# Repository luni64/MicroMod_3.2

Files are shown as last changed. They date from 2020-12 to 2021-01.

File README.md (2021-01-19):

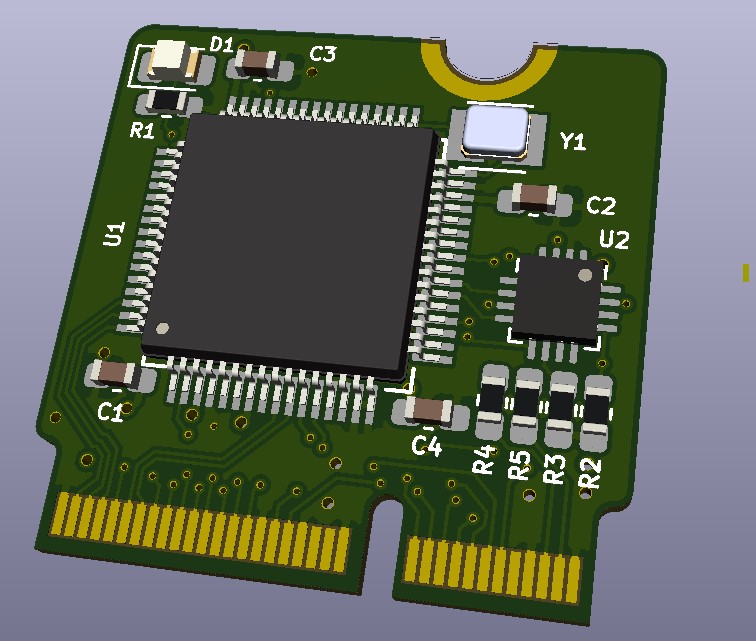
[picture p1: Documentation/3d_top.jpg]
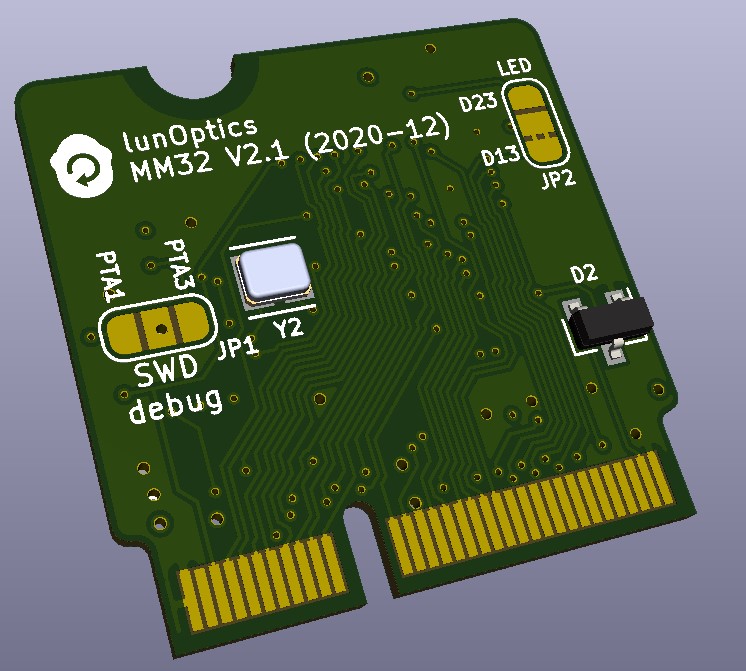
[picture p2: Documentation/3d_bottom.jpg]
3d bottom
 

# MM32
Experimental NXP MK20DX256 controller board compatible to the SparkFun MicroMod (https://www.sparkfun.com/micromod) system and the [PJRC Teensyduino](https://www.pjrc.com/teensy/teensyduino.html) ecosystem. I.e., the board fits on the SparkFun MicroMod carriers and is able to run firmware written for a Teensy 3.2.

The MM32 board utilizes the un-brickable PJRC bootloader, preprogrammed on the MKL02 chip. Please note: You need to buy the bootloader directly from PJRC (https://www.pjrc.com/store/ic_mkl02.html). It won't work with an empty MKL02.

See here https://github.com/luni64/mmStep for a compatible MicroMode stepper driver board.

## Key features:
- Contiguous **8bit port** routed to BUS0-BUS7 (Teensy: PTD0 - PTD7)
- **Two differential ADCs** mapped onto A0/A1 and ADC_D+ ADC_D-
- **True DAC** on PWM_0
- Two **UARTS** (Serial1, Serial2)
- **SPI** interface
- **CAN** Bus
- **Real time clock (RTC)**: 32.679KHz crystal and V_Bat / BAT_VIN/3
supported
- SWD_DIO, SWD_CKL, **debug interface** (bootloader chip can be disabled with a solder bridge on the back side)
- LED pin selectable (solder bridge) between D13 and D23
- Layout optimized for hand soldering

## Functional Pinout

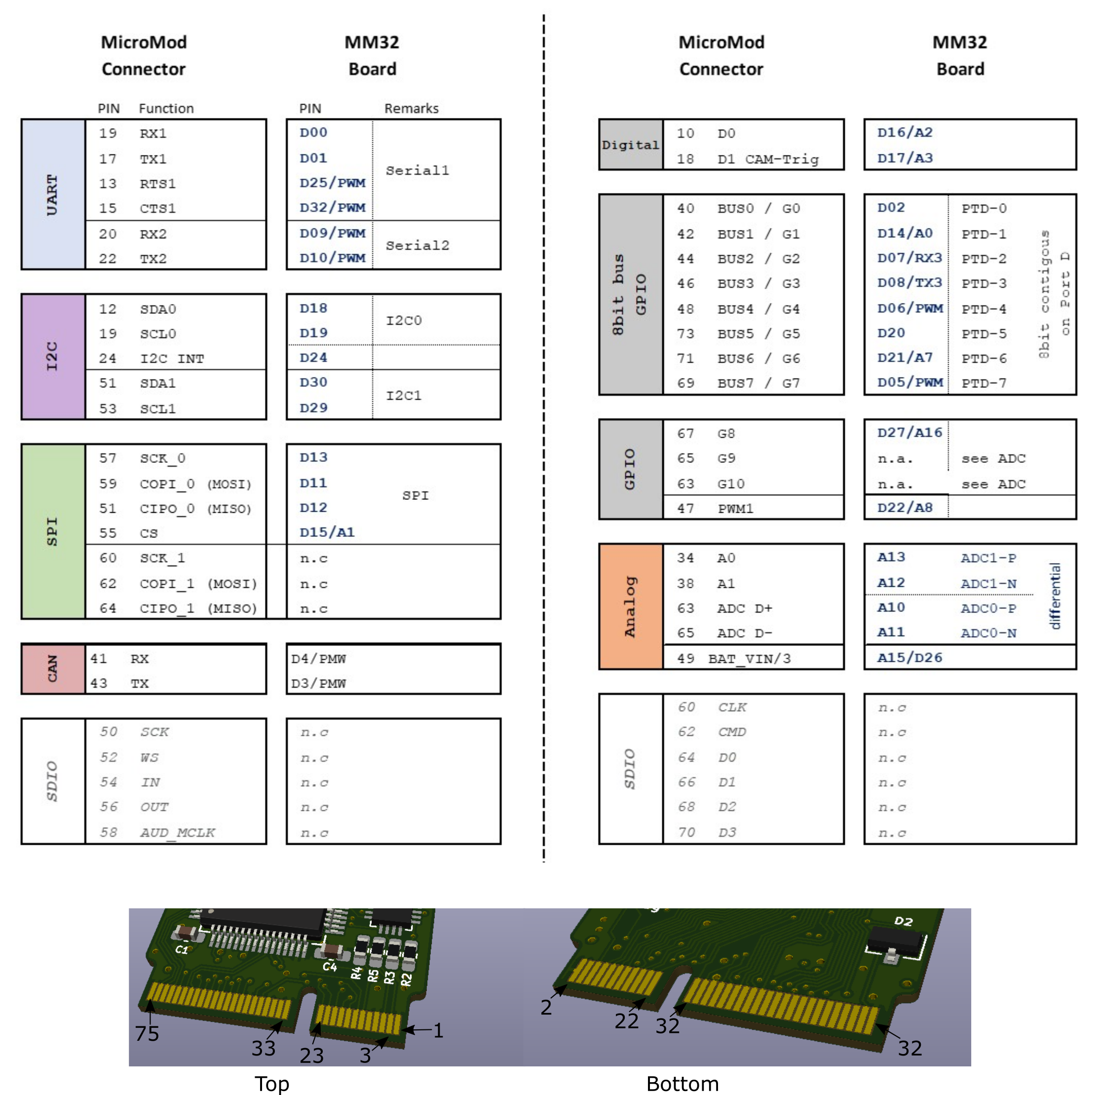
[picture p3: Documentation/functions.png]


## Production data

### PCB
Gerbers and drill files for the 4 layer, 0.8mm board can be found in the [KiCad/production](/KiCad/Production) folder. Production cost at Chinese board houses are currently (12-2020) less than USD 10 for 10 pieces plus shipping.

### Parts
Here a [link](https://octopart.com/bom-tool/5AbwHvxe) to an Octopart BOM
containing live updated prices and availability from major distributors. It also   provides links to datasheets, and technical information and alternative parts.
### Documentation
Schematic, pictures, pinouts and datasheets can be found in the documentation folder.

### Assembly
If you have experience in soldering SMD parts the assembly is straight forward. You don't need any special equipment. A standard 50W soldering iron (I use [that one](https://www.weller-tools.com/professional/EUR/en/Professional/Soldering+technology/Soldering+irons/Low-voltage+soldering+irons/Magnastat/TCP+24+) ) a magnifying glass (something like [this]( https://www.aliexpress.com/i/4000270805536.html)) and cheap head worn loupe glasses (e.g. [those](https://www.amazon.com/AORAEM-Magnifier-Glasses-Light-Extensions/dp/B01AJOD03A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)) are absolutely sufficient. Don't use a pinpoint soldering tip. You need something to transport heat quickly which is best done by a relatively large tip as shown in the video below. 

The only part I found a bit difficult to solder is the small bootloader chip (QFN16). The pads on the board are sufficiently long to solder the chip by hand in principle. However, it is a bit tedious to precisely align the chip to the pads. Start with soldering one pin, then control position and align the chip until it fits. It is helpful to apply some flux paste below the chip which will keep it in place during the alignment. Alternatively you can solder it with a hot air gun.

The rest of the parts are small but easy to solder.

Here a video showing the assembly:

MM32Assembly (https://www.youtube.com/watch?v=CCVqATbAmtM)

## Firmware

The [firmware folder](/Firmware) contains a header defining the
MicroMod <-> Teensyduino pin mappings and a helper class to access the
8bit BUS.

## Debug configuration

You can disable the bootloader by grounding its reset pin. To do so you
need to close the solder bridge on the bottom of the board as shown here:

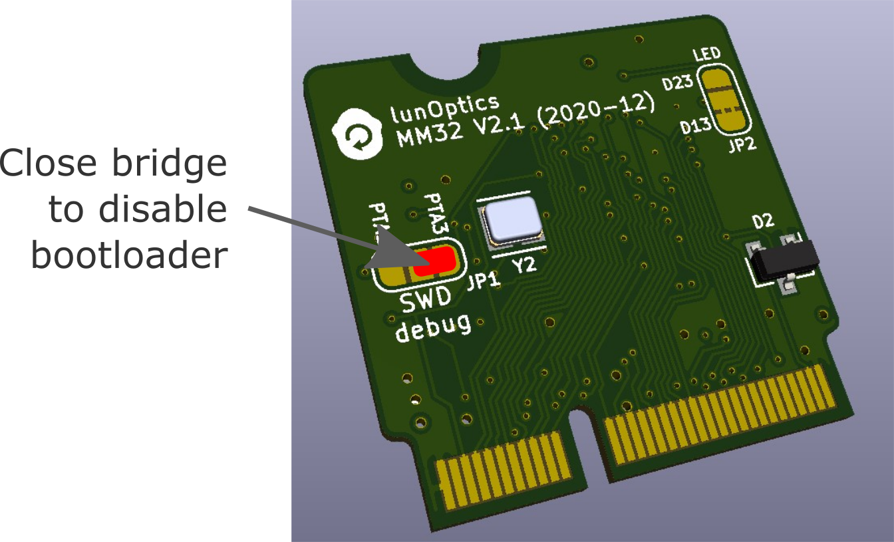
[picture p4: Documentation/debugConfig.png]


You can then connect a debug probe (e.g. a JLink-Mini EDU) to the debug
header on the carrier board.

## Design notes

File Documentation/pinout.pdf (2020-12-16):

Teensy | | | | | Teensy
n.a | 2 | 3V3 | GND | 1 | n.a
n.c | 4 | 3V3 EN | USB D+ | 3 | USB-P
RESET | 6 | /RESET | USB D- | 5 | USB-N
A17 / D28 | 8 | G11 / SWDSWO | GND | 7 | n.a
D16 | 10 | D0 | USB_VIN | 9 | n.c.
D18 | 12 | I2C SDA0 | BOOT | 11 | BL PTB2
D19 | 14 | I2C SCL0 | UART RTS1 | 13 | D25
D24 | 16 | I2C INT | UART CTS1 | 15 | D32
A3 / D17 | 18 | D1 / CAM Trig | UART TX1 | 17 | D1 / TX1
D9 | 20 | UART RX2 | UART RX1 | 19 | D0 / RX1
D10 | 22 | UART TX2 | JTAG SWDCK | 21 | PTA6
| 24 | | JTAG SWDIO | 23 | PTA7
26 25
28 27
30 29
DAC | 32 | PWM 0 | | 31
A13 | 34 | A0 | GND | 4 | n.a
n.a | 36 | GND | USBHOST D- | 35 | n.c
A12 | 38 | A1 | USBHOST D+ | 37 | n.c
PTD0 D02 | 40 | BUS 0 / G0 | GND | 39 | n.a
PTD1 D14 | 42 | BUS 1 / G1 | CAN_RX | 41 | D4
PTD2 D07 | 44 | BUS 2 / G2 | CAN_TX | 43 | D3
PTD3 D08 | 46 | BUS 3 / G3 | GND | 45 | n.a
PTD4 D06 | 48 | BUS 4 / G4 | PWM1 | 47 | D22 / A8
n.c | 50 | I2S_SCK | BAT_VIN/3 | 49 | D26 / A15
n.c | 52 | I2S_WS | I2C SDA1 | 51 | D30
n.c | 54 | I2S_IN | I2C SCL1 | 53 | D29
n.c | 56 | I2S_OUT | SPI_CS | 55 | D15
n.c | 58 | AUD_MCLK(0) | SPI SCK | 57 | D13
n.c | 60 | SPI_SCK1 / SDIO_CLK | (MOSI) SPI COPI | 59 | D11
n.c | 62 | SPI COPI1 / SDIO_CMD | (MISO) SPI CIPO | 61 | D12
n.c | 64 | SPI CIPO1 / SDIO_D0 | ADC_D+ | 63 | A10 ADC0-P
n.c | 66 | SDIO_D1 | ADC_D- | 65 | A11 ADC0-N
n.c | 68 | SDIO_D2 | G8 | 67 | D27 / A16
n.c | 70 | SPI CS1 / SDIO_D3 | BUS7 / G7 | 69 | D05 PTD7
n.c | 72 | RTC 3V BAT | BUS6 / G6 | 71 | D21 PTD6
n.a | 74 | 3V3 | BUS5 / G5 | 73 | D20 PTD5
GND | 75 | n.a Serial2 | Serial 1 JTAG I2C 0

n.a

Key
Key

n.a

## MicroMod Pinout

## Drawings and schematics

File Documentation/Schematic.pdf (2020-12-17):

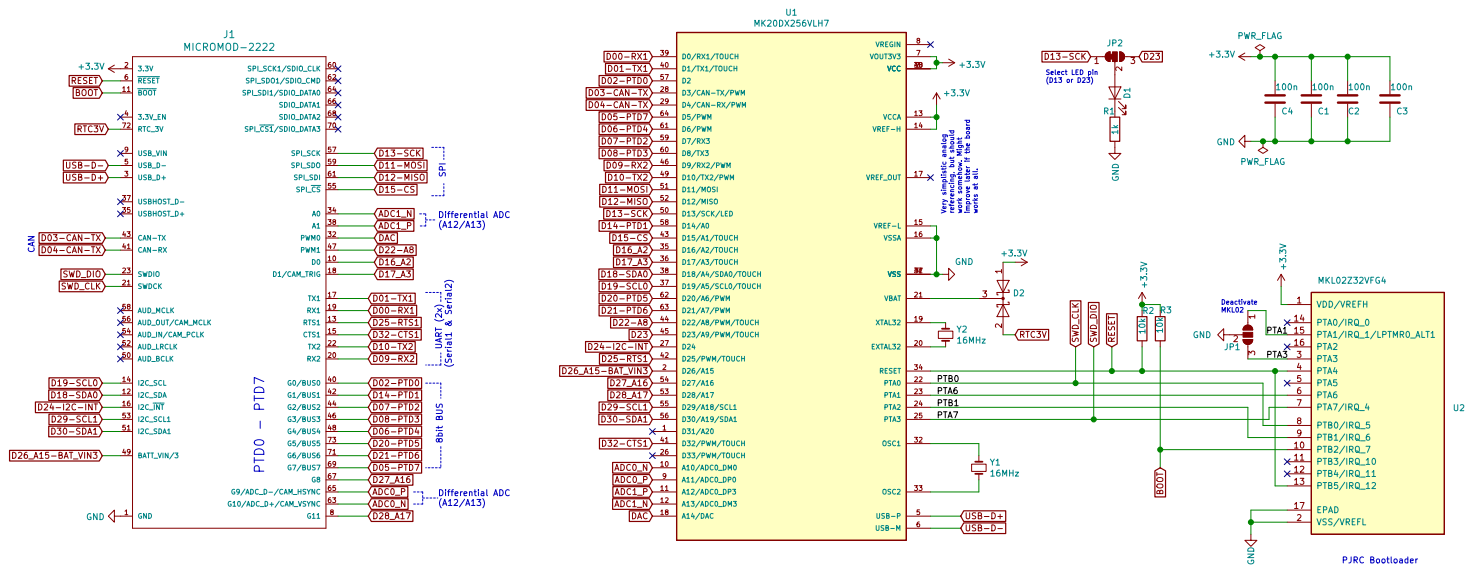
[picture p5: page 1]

D07-PTD2 ADC1_N
(uses Sparkfun recommend connector pin assignment) Similar to T3.2 GND

File: TeensyMM.sch Sheet: / Lunoptics

Id: 1/1 Title: MicroMode32 experimental board

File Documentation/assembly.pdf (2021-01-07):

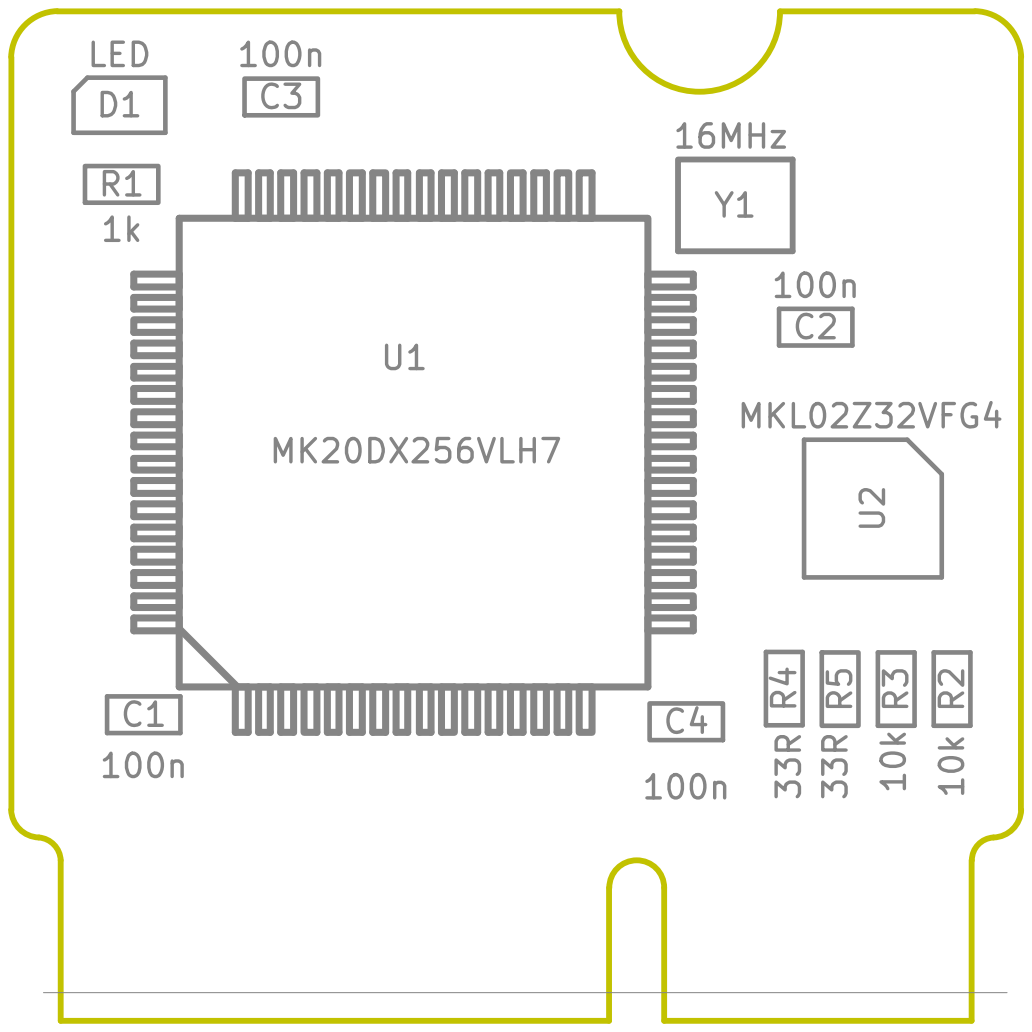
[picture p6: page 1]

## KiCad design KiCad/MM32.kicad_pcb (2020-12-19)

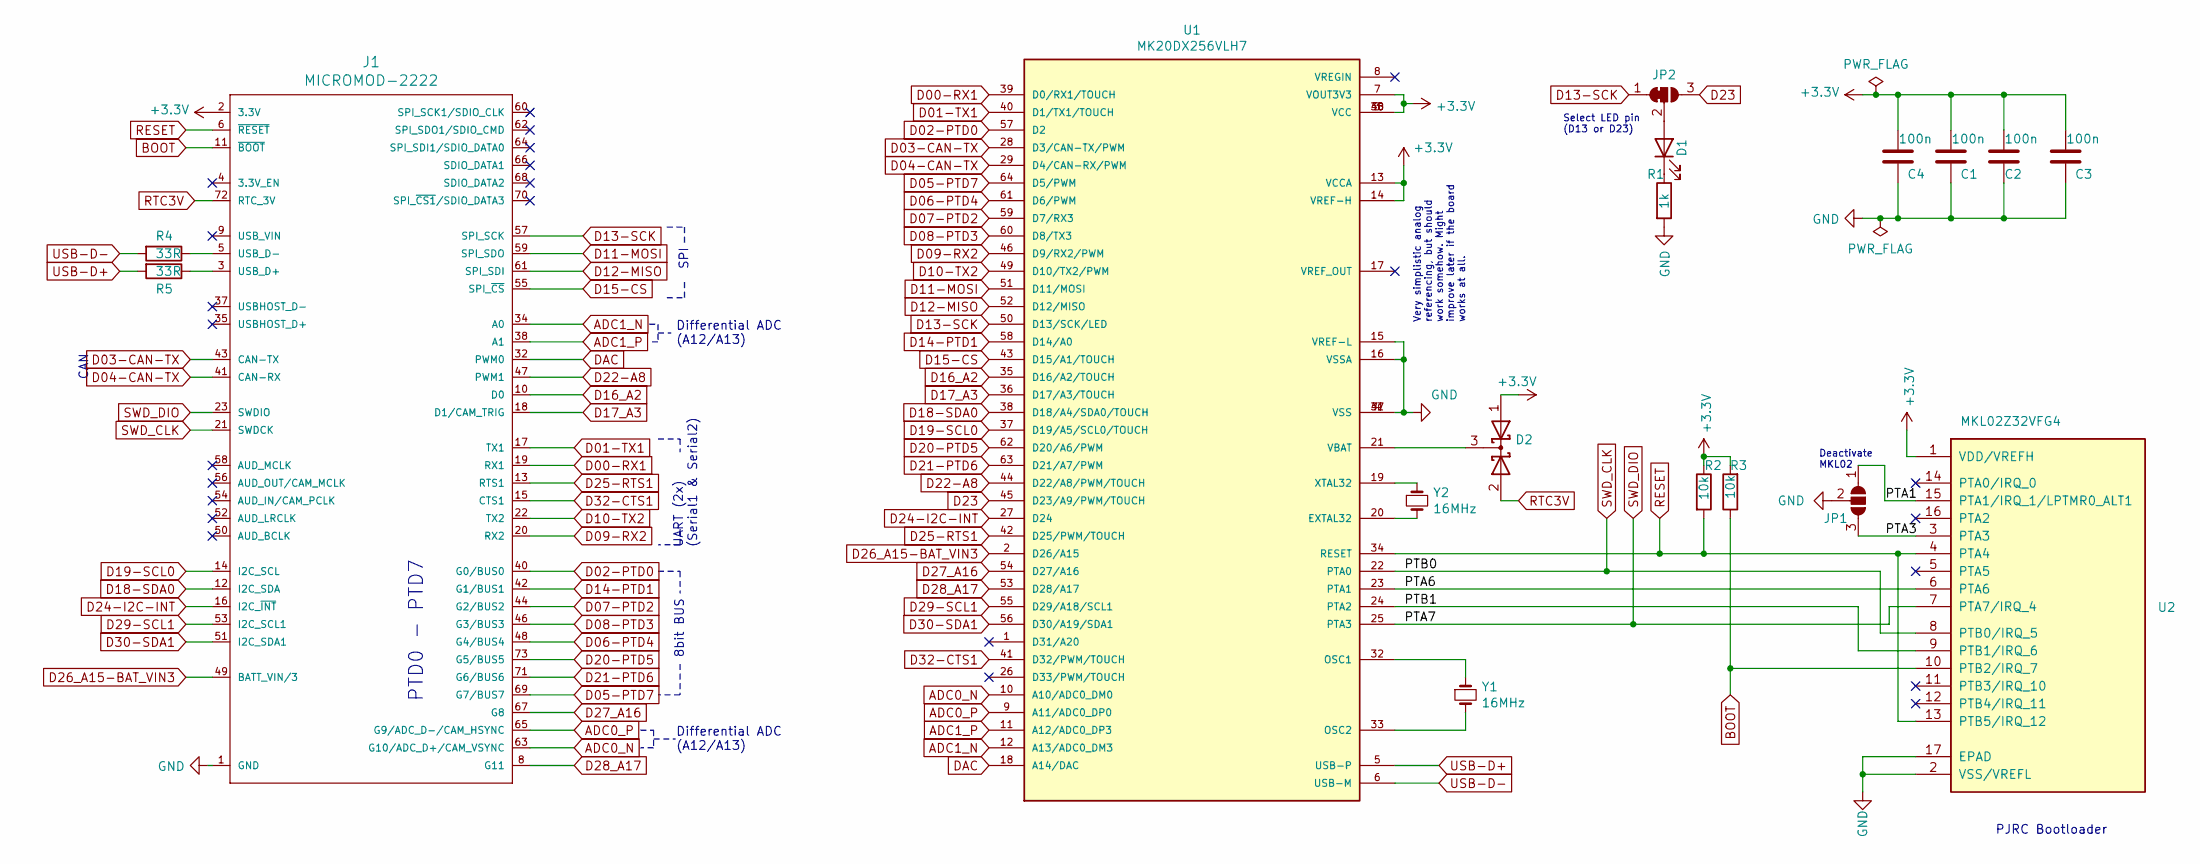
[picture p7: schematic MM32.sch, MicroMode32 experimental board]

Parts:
C1, C2, C3, C4: 100n; C_0603_1608Metric_Pad1.08x0.95mm_HandSolder
D1: LED; LED_0805_2012Metric_Pad1.15x1.40mm_HandSolder
D2: D_Schottky_x2_KCom_AAK; SOT-23
J1: MICROMOD-2222; M.2-CARD-E-22
JP1: SolderJumper_3_Open; SolderJumper-3_P1.3mm_Open_RoundedPad1.0x1.5mm
JP2: SolderJumper_3_Bridged12; SolderJumper-3_P1.3mm_Bridged12_RoundedPad1.0x1.5mm
R1: 1k; R_0603_1608Metric_Pad1.05x0.95mm_HandSolder
R2, R3: 10k; R_0603_1608Metric_Pad1.05x0.95mm_HandSolder
R4, R5: 33R; R_0603_1608Metric_Pad1.05x0.95mm_HandSolder
U1: MK20DX256VLH7; QFP50P1200X1200X160-64N
U2: MKL02Z32VFG4; QFN-16-1EP_3x3mm_P0.5mm_EP1.9x1.9mm
Y1, Y2: 16MHz; OSC_XRCHA16M000F0A01R0

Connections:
+3V3: C1.1, C2.1, C3.1, C4.1, D2.1 (A), J1.2 (3.3V), J1.74 (3.3V), R2.1, R3.2, U1.3 (VCC), U1.7 (VOUT3V3), U1.13 (VCCA), U1.14 (VREF-H), U1.30 (VCC), U1.48 (VCC), U2.1 (VDD/VREFH)
/PTA1: JP1.1 (A), U2.15 (PTA1/IRQ_1/LPTMR0_ALT1)
/PTA3: JP1.3 (B), U2.3 (PTA3)
/PTA6: U1.23 (PTA1), U2.6 (PTA6)
/PTB1: U1.24 (PTA2), U2.9 (PTB1/IRQ_6)
ADC0_N: J1.63 (G10/ADC_D+/CAM_VSYNC), U1.10 (A10/ADC0_DM0)
ADC0_P: J1.65 (G9/ADC_D-/CAM_HSYNC), U1.9 (A11/ADC0_DP0)
ADC1_N: J1.34 (A0), U1.12 (A13/ADC0_DM3)
ADC1_P: J1.38 (A1), U1.11 (A12/ADC0_DP3)
BOOT: J1.11 (~BOOT~), R3.1, U2.10 (PTB2/IRQ_7)
D00-RX1: J1.19 (RX1), U1.39 (D0/RX1/TOUCH)
D01-TX1: J1.17 (TX1), U1.40 (D1/TX1/TOUCH)
D02-PTD0: J1.40 (G0/BUS0), U1.57 (D2)
D03-CAN-TX: J1.43 (CAN-TX), U1.28 (D3/CAN-TX/PWM)
D04-CAN-TX: J1.41 (CAN-RX), U1.29 (D4/CAN-RX/PWM)
D05-PTD7: J1.69 (G7/BUS7), U1.64 (D5/PWM)
D06-PTD4: J1.48 (G4/BUS4), U1.61 (D6/PWM)
D07-PTD2: J1.44 (G2/BUS2), U1.59 (D7/RX3)
D08-PTD3: J1.46 (G3/BUS3), U1.60 (D8/TX3)
D09-RX2: J1.20 (RX2), U1.46 (D9/RX2/PWM)
D10-TX2: J1.22 (TX2), U1.49 (D10/TX2/PWM)
D11-MOSI: J1.59 (SPI_SDO), U1.51 (D11/MOSI)
D12-MISO: J1.61 (SPI_SDI), U1.52 (D12/MISO)
D13-SCK: J1.57 (SPI_SCK), JP2.1 (A), U1.50 (D13/SCK/LED)
D14-PTD1: J1.42 (G1/BUS1), U1.58 (D14/A0)
D15-CS: J1.55 (SPI_~CS~), U1.43 (D15/A1/TOUCH)
D16_A2: J1.10 (D0), U1.35 (D16/A2/TOUCH)
D17_A3: J1.18 (D1/CAM_TRIG), U1.36 (D17/A3/TOUCH)
D18-SDA0: J1.12 (I2C_SDA), U1.38 (D18/A4/SDA0/TOUCH)
D19-SCL0: J1.14 (I2C_SCL), U1.37 (D19/A5/SCL0/TOUCH)
D20-PTD5: J1.73 (G5/BUS5), U1.62 (D20/A6/PWM)
D21-PTD6: J1.71 (G6/BUS6), U1.63 (D21/A7/PWM)
D22-A8: J1.47 (PWM1), U1.44 (D22/A8/PWM/TOUCH)
D23: JP2.3 (B), U1.45 (D23/A9/PWM/TOUCH)
D24-I2C-INT: J1.16 (I2C_~INT~), U1.27 (D24)
D25-RTS1: J1.13 (RTS1), U1.42 (D25/PWM/TOUCH)
D26_A15-BAT_VIN3: J1.49 (BATT_VIN/3), U1.2 (D26/A15)
D27_A16: J1.67 (G8), U1.54 (D27/A16)
D28_A17: J1.8 (G11), U1.53 (D28/A17)
D29-SCL1: J1.53 (I2C_SCL1), U1.55 (D29/A18/SCL1)
D30-SDA1: J1.51 (I2C_SDA1), U1.56 (D30/A19/SDA1)
D32-CTS1: J1.15 (CTS1), U1.41 (D32/PWM/TOUCH)
DAC: J1.32 (PWM0), U1.18 (A14/DAC)
GND: C1.2, C2.2, C3.2, C4.2, J1.1 (GND), J1.7 (GND), J1.33 (GND), J1.36 (GND), J1.39 (GND), J1.45 (GND), J1.75 (GND), JP1.2 (C), R1.2, U1.4 (VSS), U1.15 (VREF-L), U1.16 (VSSA), U1.31 (VSS), U1.47 (VSS), U2.2 (VSS/VREFL), U2.17 (EPAD)
unnamed: D1.1 (K), R1.1
unnamed: D1.2 (A), JP2.2 (C)
unnamed: D2.3 (K), U1.21 (VBAT)
unnamed: J1.3 (USB_D+), R5.1
unnamed: J1.5 (USB_D-), R4.1
unnamed: U1.19 (XTAL32), Y2.1
unnamed: U1.20 (EXTAL32), Y2.2
unnamed: U1.32 (OSC1), Y1.1
unnamed: U1.33 (OSC2), Y1.2
RESET: J1.6 (~RESET~), R2.2, U1.34 (RESET), U2.4 (PTA4), U2.13 (PTB5/IRQ_12)
RTC3V: D2.2 (A), J1.72 (RTC_3V)
SWD_CLK: J1.21 (SWDCK), U1.22 (PTA0), U2.8 (PTB0/IRQ_5)
SWD_DIO: J1.23 (SWDIO), U1.25 (PTA3), U2.7 (PTA7/IRQ_4)
USB-D+: R5.2, U1.5 (USB-P)
USB-D-: R4.2, U1.6 (USB-M)

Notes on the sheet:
PTD0 - PTD7
SPI
UART (2x) (Serial1 & Serial2)
8bit BUS
CAN
Deactivate MKL02
PJRC Bootloader
Very simplistic analog referencing, but should work somehow. Might improve later if the board works at all.
Select LED pin (D13 or D23)
Differential ADC (A12/A13)

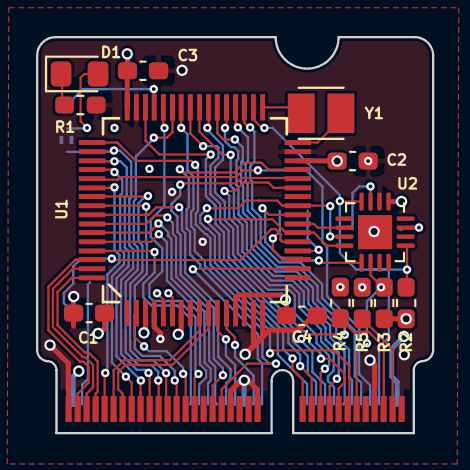
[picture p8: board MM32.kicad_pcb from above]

Board: 4 copper layers, 22.0 x 22.0 mm, 19 parts (0 on the bottom side), 59 nets.

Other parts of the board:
e: LOGO; logo

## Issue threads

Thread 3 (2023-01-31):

Project status - Tested?

samuk, 2023-01-31:
Did you ever make/test these?

I have a project that requires a Teensy in Micromod format, just wondering if these could be fabbed cheaper than the 'official' ones?

This is the project: https://github.com/rosmo-robot/smartcar_shield/blob/master/README.md#smartcar-10-current

luni64, 2023-01-31:
Yes, I made a couple of them.  The "official" ones are T4 based, mine are T3.1 based. If you want to save money I assume you'd need really high volume to compete with sparkFun's pricing.

samuk, 2023-01-31:
Thanks, you are probably correct. Do you happen to remember how much the ones you made worked out to?

luni64, 2023-02-01:
There is a link to a live costed BOM in the readme. IIRC it was about 15EUR when I did the build. I did the assmembly myself so I don't know what this would cost these days.

samuk, 2023-02-01:
Thanks, will check the BOM

Closed 2023-02-01.

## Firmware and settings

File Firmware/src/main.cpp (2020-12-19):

#include "Arduino.h"
#include "mm.h"
//using namespace MM32;

MM32::BUS bus;

void setup()
{
    pinMode(bus, OUTPUT);
    bus = 0xA2;

    pinMode(bus, INPUT);
}

void loop()
{
    uint8_t value = bus;
    Serial.println(value);

    digitalWriteFast(LED_BUILTIN, !digitalReadFast(LED_BUILTIN));
    delay(150);
}

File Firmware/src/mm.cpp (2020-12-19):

#include "mm.h"

namespace MM32
{
    void BUS::pinMode(int mode) const
    {
        for (uint8_t pin : {2, 14, 7, 8, 6, 20, 21, 5})
        {
            ::pinMode(pin, mode);
        }
    }

    void BUS::operator=(uint8_t value) const
    {
        GPIOD_PDOR = value;
    }

    BUS::operator uint8_t() const
    {
        return GPIOD_PDIR;
    }



    void pinMode(const BUS& bus, int mode)
    {
        bus.pinMode(mode);
    }
}

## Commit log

2020-12-14 Added schematic
2020-12-14 4 layer design WIP
    [TeensyMM.kicad_pcb]
2020-12-16 finalized 4layer design
    [TeensyMM-B_Mask.gbs, TeensyMM-B_SilkS.gbo, TeensyMM-Bottom.gbl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]
2020-12-16 fixed error in schematic
2020-12-16 Solder mask over solder bridges
    [TeensyMM.kicad_pcb]
2020-12-16 Added RTC crystal, and v_bat circuitry. Needs cleanup
    [TeensyMM.kicad_pcb, TeensyMM.sch]
2020-12-17 Cleanup board and gerbers
    [TeensyMM-B_Mask.gbs, TeensyMM-B_SilkS.gbo, TeensyMM-Bottom.gbl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]
2020-12-17 Added Series Resistors on USB lines
    [TeensyMM.kicad_pcb]
2020-12-18 Rename KiCad files
    [MM32.kicad_pcb, MM32.sch]
2021-01-07 Added assembly video
